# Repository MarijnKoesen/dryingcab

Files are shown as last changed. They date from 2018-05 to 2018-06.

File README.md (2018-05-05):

# Drying cabinet v2.0



This is my drying cabinet / curing chamber or just call it connected fridge which keeps the 
temperature and humidity levels (inside the fridge) stable between some configured thresholds.

I use this cabinet to make my own cured ham & dried sausage.

This project is built on an Arduino Mega in combination with a DHT22 temperature/humidity sensor, 4 way relay 
and an ESP8266 (WiFi) adapter to create the connected fridge.

For more information on design (decisions) etc, check out src/dryingcab.ino's comment at the top.

## Result

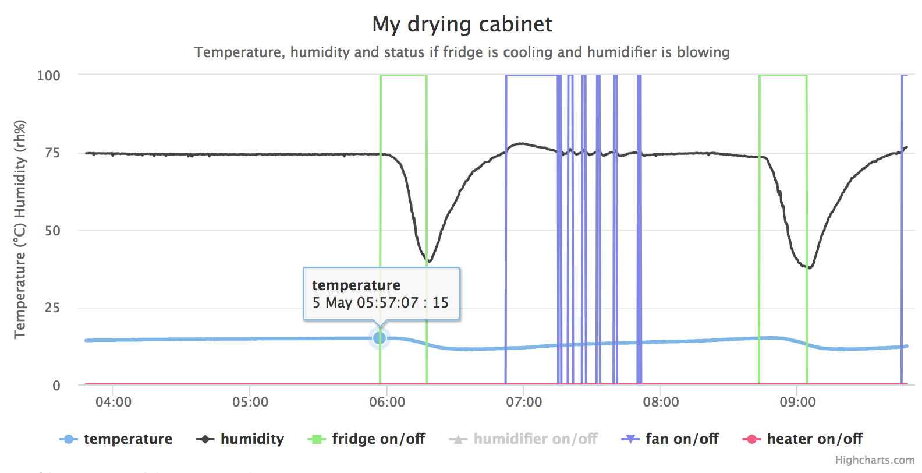
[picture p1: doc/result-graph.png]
Result graph


Here you can see some graphs from the fridge. 

Notice the temperature keeps stable between 13 and 15 degrees and the humidity
between 50 and 75 percent.

When the temperature gets too high, the fridge turns on, causing the humitity to 
drop. 

After the temperature is at the lower threshold (13), the fridge is turned off again and
the humidity starts to rise again, actually going a bit higher then we want. 

At this time the fan turns on, and blows out some of the humid air, stabalizing 
everything again. 

Now the temperature slowly rises (because it's hotter outside) until it gets above
the threshold again and the whole proces starts over.

## Connection diagram

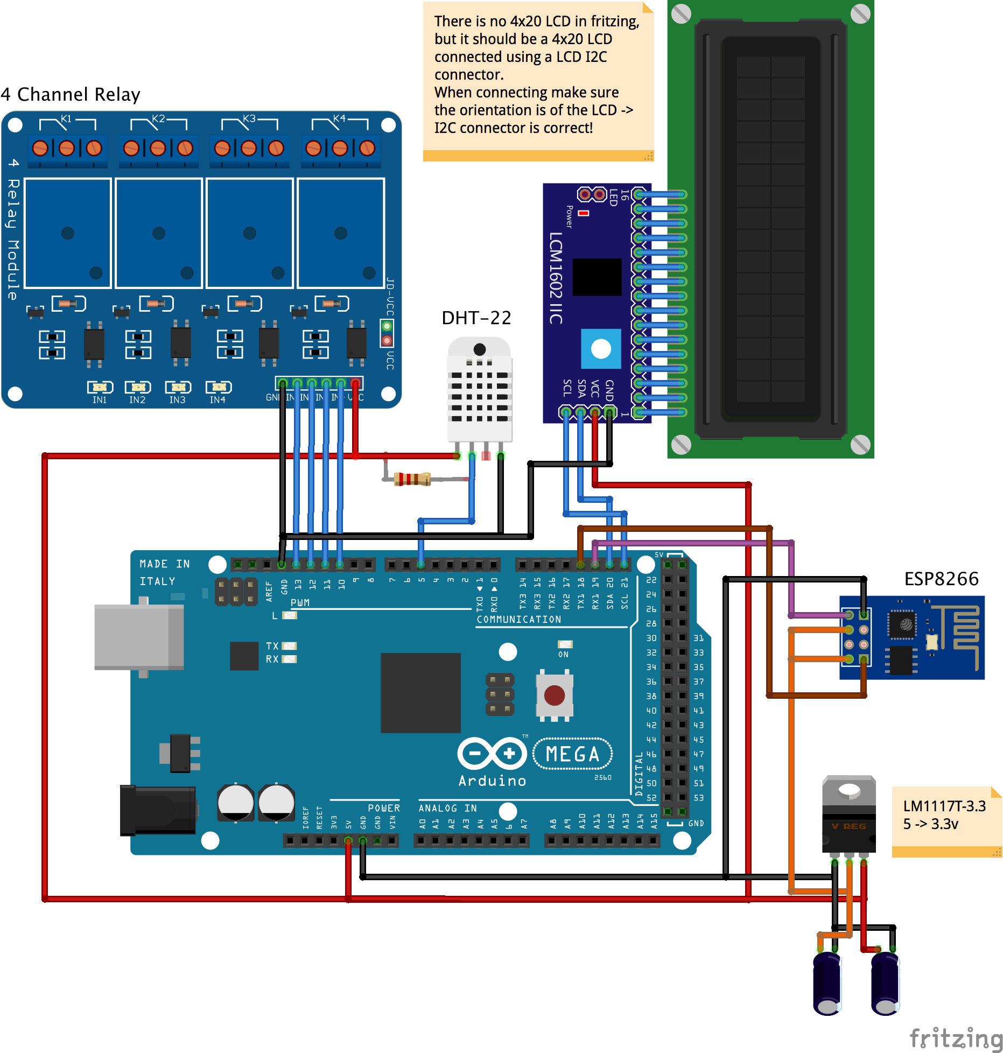
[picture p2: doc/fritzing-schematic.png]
Connection diagram


## Part list

- 1x Arduino Mega
- 1x DHT-22
- 1x [LM1117T-3.3](https://www.vanallesenmeer.nl/LM1117T-3.3-Spanningsregelaar%283.3v%29)
- 1x [20x4 LCD](https://www.vanallesenmeer.nl/LCD-Display-2004A-20x4-wit-op-blauw-)
- 1x [LCD I2C](https://www.vanallesenmeer.nl/LCD-I2C-interface-)
- 1x [ESP8266](https://www.vanallesenmeer.nl/ESP8266-Serial-Wireless-WIFI-Module)
- 1x [4 channel relay board](https://www.vanallesenmeer.nl/Relais-board-4-kanaals-5V-)
- 1x 10k resistor
- 2x 10uf cap

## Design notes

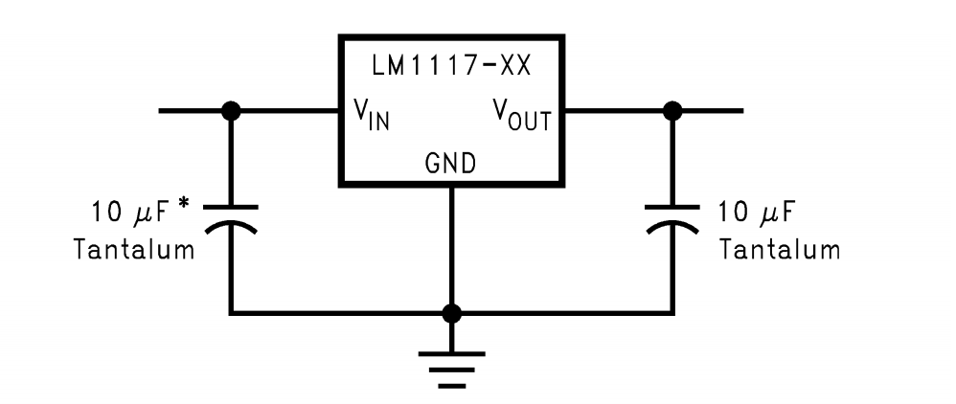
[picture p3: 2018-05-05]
doc/lm1117-schematic.png

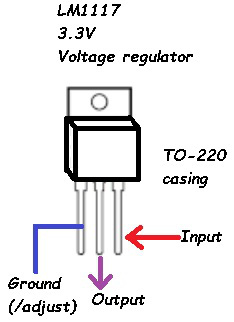
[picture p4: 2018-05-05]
doc/lm1117-3-3v-voltage-regulator-pinout.jpg

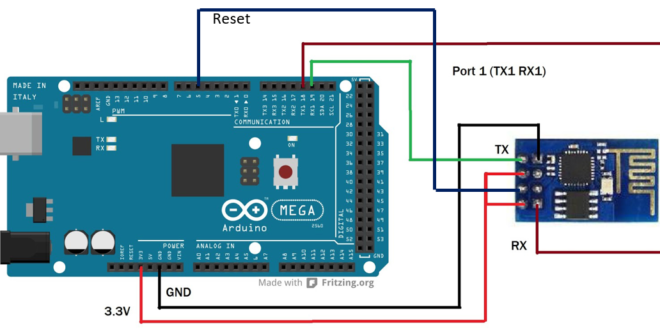
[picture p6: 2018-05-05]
doc/mega_esp8266.png

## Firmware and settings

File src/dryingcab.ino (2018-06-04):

// Drying cabinet v2.0
//
// My arduino drying / controlled environment cabinet. This software uses
// as Arduino Mega in combination with a DHT22, 4 way relay and an ESP8266
// (WiFi) adapter to created a connected fridge which keeps the temperature
// and humidity levels stable between the configured thresholds.
//
// IMPORTANT: 1) for this to work correctly we need proper watchdog support
//
// Connection instructions (see dryingcab.h for details, or to change pins):
// - Connect DHT22 data to pin 5
// - Connect the relay for the fridge to pin PIN_RELAY_FRIDGE (13)
// - Connect the relay for the humidifier to pin PIN_RELAY_HUMIDIFIER (12)
// - Connect the relay for the fan to pin PIN_RELAY_FAN (11)
// - Connect the relay for the heater (black lamp) to pin PIN_RELAY_HEATER (10)
// - Connect the relay further more to gnd and +5v
// - Connect the 4x20 I2C LCD to the SDA(20) & SCL (21), gnd and +5v
// - For further connection instructions see the connection diagram in this project (/doc)

// Notes on the algorithm:
// - 30 seconds was too long, we humidified for too long, getting a humidity that was too high
// - 15 seconds is working fine
// - We don't want to go too short, to avoid turning on the electric stuff too often/soon after shutting it down
// - When the humidity is too high we put on the fan so that we blow out wet air, and suck in new warmer, dryer air
// - To ensure we have the recommend airflow we turn the fan on for 1 second every 15 seconds, this circulates the air

// Notes about the construction:
// - About the fan:
// -- Make sure the fan is pointed so that it's sucking air out, otherwise you will get overpressure
// -- Make another hole on the opposite side (diagonally) of the fan, so that new air is sucked in there
// -- Place the fan at the top, so that it sucks warm air out
// -- Create the other (small) hole in the bottom

// My problems and challenges when developing this, what worked, and what didn't with regards to the ethernet
// - In the previous versions I was using a Enc28J60 UTP board, but there were a lot of problems with this, see previous
//   versions of this project, in this commentblock, where it's explained in more detail
// - Also I wanted to have control over de settings from the outside, without needing to re-program the fridge
//   to achieve this I wanted to add an LCD and some buttons. So I can control settings easily.
// -- Currently there is no support for the buttons though, this will be done in a later stage as the fridge is still
//    busy with my capocollo which is more important and cannot be interrupted ;-)
// - To get rid of the Enc28J60 board I decided to use the ESP8266 WiFi module instead
// - Connecting to Enc28J60 is done using a Serial connection, but since the Arduino UNO only has 1 Serial connection
//   it's hard to debug and use the WiFi at the same time. I tried to user SoftwareSerial, but that was just a PITA.
//   First because Enc28J60 doesn't really like it, as the best baud rate is 115200, but SoftwareSerial only supports
//   up to 9600. Apart from that I couldn't really get it to work. So I decided to change it, and go with Arduino Mega instead
// - Currently i'm running with watchdog enabled
// -- This may be a bit of legacy, as I needed it for the Enc28J60 board, but I think it's good practice to keep this running
//    so that for what ever reason something goes wrong/is hanging, the arduino will just be reset and will start again.
// -- The idea is that I set watchdog on 8sec, so if I don't give the watchdog an ok every 8 seconds it reboots the arduino
// - The project is developed in Atom using PlatformIO, with this setup i'm able to create a better project
//   structure with separate files, includes, libraries and a makefile that I can run. I prefer this a lot over the
//   standard Arduino IDE, which works, but I don't really like it, you can't even format source code in it for example.
// - For the WiFi I ended up using the Arduino WiFiEsp library, the stock Android library doesn't allow you to specify
//   which Serial port to use, and since I'm on a mega a want to be able to specify Serial1.
// - The ESP8266 needs 3.3V, but the Arduino can't supply enough ampere on the 3.3v port, so I read online
// -- To fix thix we need to create a voltage devider so we can go from the 5v output 3.3v
//    as the 5v output _is_ able to supply enough current
// -- To make out lives easier we're using the the LM1117T-3.3 with fixed 3.3v output
// - If I start to see problems with WiFi I can still try to hook up the reset pin of the esp8266 to a digital pin
//   on the mega, say pin 1, then you can do the following:
//     // In setup();
//     pinMode(1, OUTPUT);
//     // And thenn something like this:
//     void resetEsp() { digitalWrite(1, HIGH); delay(1000); digitalWrite(1, LOW); }
//   as per: http://www.galaxysofts.com/new/master-reset-esp8266-wifi-module-using-arduino-mega-2560/




#include "dryingcab.h"

Settings settings;
Status status;


// ==========================
// DHT (temp/humidity sensor)
// ==========================
// Initialize DHT sensor for normal 16mhz Arduino
// NOTE: For working with a faster chip, like an Arduino Due or Teensy, you
// might need to increase the threshold for cycle counts considered a 1 or 0.
// You can do this by passing a 3rd parameter for this threshold.  It's a bit
// of fiddling to find the right value, but in general the faster the CPU the
// higher the value.  The default for a 16mhz AVR is a value of 6.  For an
// Arduino Due that runs at 84mhz a value of 30 works.
// Example to initialize DHT sensor for Arduino Due:
//DHT dht(DHTPIN, DHTTYPE, 30);
#include <DHT.h>
DHT dht(PIN_DHT, DHTTYPE);

// ==========================
// Setup out periherals
// ==========================
void setup() {
    // avoid reset loops
    MCUSR = 0;

    // https://bigdanzblog.wordpress.com/2014/10/24/arduino-watchdog-timer-wdt-example-code/
    // immediately disable watchdog timer so set will not get interrupted
    wdt_disable();
    wdt_reset();

    // Now init the lcd
    lcd_init();

    // Initialize the temp+humidity sensor
    dht.begin();

    pinMode(PIN_RELAY_FRIDGE, OUTPUT);
    pinMode(PIN_RELAY_HUMIDIFIER, OUTPUT);
    pinMode(PIN_RELAY_FAN, OUTPUT);
    pinMode(PIN_RELAY_HEATER, OUTPUT);

    // We need to put the relays in an 'off' state, else they will be switched on by (Arduino's pin) default and, potentially, in the first loop
    // go off again as they don't need to be on, causing a off/on/off switch in a short amount of time which we want to prevent
    turnOff(PIN_RELAY_FRIDGE);
    turnOff(PIN_RELAY_HUMIDIFIER);
    turnOff(PIN_RELAY_FAN);
    turnOff(PIN_RELAY_HEATER);

    // And set default settings
    settings.minHumidity = 50;
    settings.maxHumidity = 75;

    settings.minTemp = 13;
    settings.maxTemp = 15;

    status.humidity = 75.7;
    status.temperature = 13.5;

    //   // The following forces a pause before enabling WDT. This gives the IDE a chance to
    //   // call the bootloader in case something dumb happens during development and the WDT
    //   // resets the MCU too quickly. Once the code is solid, remove this.
    delay(2000);
    wdt_enable(WDTO_8S);
}

// ==========================
// Our main application loop
// ==========================
void loop() {
  debugln("\n\nStarting lcd...");
  LcdOutput lcdOutput;
  debugln("Lcd started");
  debugln("Lcd outputing..");
  lcdOutput.output(status, settings);
  debugln("Lcd outputted");

  debugln("Create wifi");
  WiFiOutput wifiOutput(WIFI_NETWORK, WIFI_PASSWORD);
  debugln("Wifi created...");
  wifiOutput.connect();
  // debugln("Wifi connected...");
  // wifiOutput.output(status, settings);
  // debugln("Create outputtedd...");

  while(1) {
    readSensors();
    processSensorData();
    updateStatus();

    lcdOutput.output(status, settings);
    wifiOutput.output(status, settings);

    #ifdef DEBUG
    // Move to DebugOutput.output()
      Serial.print("Temp: ");
      Serial.println(status.temperature);

      Serial.print("Humidity: ");
      Serial.println(status.humidity);
    #endif

    // Wait for 15 seconds, and check again so that we don't turn on/off the fridge constantly
    //
    // But if we'd delay(30000) our network connection would get closed/fucked up, so we need
    // to keep the network alive by sleeping shortly, and checking for packets, this way the
    // network stays alive
    int sleepInSeconds = 15;

    for (int i = 0; i < sleepInSeconds; i++) {
      // Reset the watchdog, so that the arduino will not get reset
      wdt_reset();

      delay(1000);

      if (status.statusFan == true) {
        // If we have a high humidity and the fan is already on, keep the fan on for 15 seconds, to try to get the humidity down
      } else {
        // If we have a proper humidity, turn the fan on for 1 second every 15 seconds to ensure we have some airflow
        switch(i) {
          case 0:
            turnOn(PIN_RELAY_FAN);
            break;

          case 1:
            turnOff(PIN_RELAY_FAN);
            break;
        }
      }
    }
  }
}

void readSensors() {
  status.temperature = getTemperatureInCelcius();
  status.humidity = getHumidity();
}

void processSensorData() {
  if (status.temperature >= settings.maxTemp) {
    turnOn(PIN_RELAY_FRIDGE);
  }

  if (status.temperature < settings.minTemp) {
    turnOff(PIN_RELAY_FRIDGE);
  }

 if (status.humidity < settings.minHumidity) {
    turnOn(PIN_RELAY_HUMIDIFIER);
  }

  if (status.humidity > settings.maxHumidity) {
    turnOff(PIN_RELAY_HUMIDIFIER);
  }

  if (status.humidity > settings.maxHumidity) {
    // Currently the outside humidity is higher then inside the fridge
    // so turning on the fan only makes it worse.
    // TODO: add another temp/humidty sensor outside of the fridge, and only
    // turn on the fan is the outside humidity is lower than inside
    //turnOn(PIN_RELAY_FAN);
  } else {
    //turnOff(PIN_RELAY_FAN);
  }
}

void updateStatus() {
  status.statusFridge = digitalRead(PIN_RELAY_FRIDGE) == LOW;
  status.statusHumidifier = digitalRead(PIN_RELAY_HUMIDIFIER) == LOW;
  status.statusFan = digitalRead(PIN_RELAY_FAN) == LOW;
  status.statusHeater = digitalRead(PIN_RELAY_HEATER) == LOW;
}

//
// int failedLogTries = 0;
// void sendLogData() {
//   // generate two fake values as payload - by using a separate stash,
//   // we can determine the size of the generated message ahead of time
//   #ifdef DEBUG
//   Serial.println(F("GO"));
//   #endif
//
// //   if (client.connect(server, 80)) {
// //     client.print(F("GET /push-status.php?"));
// //
// //     client.print(F("temperature="));
// //     client.print(logData.fridgeTemperature);
// //
// //     client.print(F("&humidity="));
// //     client.print(logData.humidity);
// //
// //     client.print(F("&status_fridge="));
// //     client.print(logData.statusFridge == 1 ? F("1") : F("0"));
// //
// //     client.print(F("&status_humidifier="));
// //     client.print(logData.statusHumidifier == 1 ? F("1") : F("0"));
// //
// //     client.print(F("&status_fan="));
// //     client.print(logData.statusFan == 1 ? F("1") : F("0"));
// //
// //     client.print(F("&status_heater="));
// //     client.print(logData.statusHeater == 1 ? F("1") : F("0"));
// //
// //     client.print(F(" HTTP/1.1\n"));
// //
// //     client.print(F("HOST: droogkast.pruts0r.nl\n\n"));
// //     client.stop();
// //   } else {
// //     #ifdef DEBUG
// //     Serial.println(F("ERROR: Cannot connect to server to push status! Restarting the Enc28J60.."));
// //     #endif
// //
// //     failedLogTries++;
// //     if (failedLogTries > 3) {
// //       reboot = true;
// //     }
// //
// //     // Try to re-init our network module if it fails, next time round it should be fine again...
// //     // Found: http://www.tweaking4all.com/hardware/arduino/arduino-enc28j60-ethernet/
// //     client.stop();
// //     //Enc28J60.init(mymac);
// //   }
// }
//
//
// // void connectLanWithDhcp() {
// // #ifdef DEBUG
// //   Serial.println(F("Starting network connection..."));
// // #endif
// //
// //   Ethernet.begin(mymac);
// //
// // #ifdef DEBUG
// //   Serial.println(F("Network started.]"));
// //   Serial.print(F("IP Address        : "));
// //   Serial.println(Ethernet.localIP());
// //   Serial.print(F("Subnet Mask       : "));
// //   Serial.println(Ethernet.subnetMask());
// //   Serial.print(F("Default Gateway IP: "));
// //   Serial.println(Ethernet.gatewayIP());
// //   Serial.print(F("DNS Server IP     : "));
// //   Serial.println(Ethernet.dnsServerIP());
// // #endif
// // }

void turnOn(int pin)
{
  digitalWrite(pin, LOW);
}

void turnOff(int pin)
{
  digitalWrite(pin, HIGH);
}

float getTemperatureInCelcius()
{
  return dht.readTemperature();
}

/**
 * Reading temperature or humidity takes about 250 milliseconds!
 * Sensor readings may also be up to 2 seconds 'old' (its a very slow sensor)
 */
float getHumidity()
{
  return dht.readHumidity();
}

void showDebugModeOnLcd()
{
  lcd.clear();
  lcd.setCursor(0, 0);
  lcd.print(F("RUNNING IN DEBUG MODE!!"));
}

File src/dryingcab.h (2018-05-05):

#ifndef DRYINGCAB_H
#define DRYINGCAB_H

// Arduino includes
#include <Arduino.h>
#include <avr/wdt.h> // Watchdog

// DryincCab includes
#include "Settings.h"
#include "WiFiConfig.h"
#include "Status.h"
#include "Output/LcdOutput.h"
#include "Output/WiFiOutput.h"

// ========================
// RELAY
// ========================

#define PIN_RELAY_FRIDGE        13
#define PIN_RELAY_HUMIDIFIER    12
#define PIN_RELAY_FAN           11
#define PIN_RELAY_HEATER        10

// ========================
// THERMOMETER / HYDROMETER
// ========================

#define PIN_DHT 5       // what pin we're connected to
#define DHTTYPE DHT22   // DHT11 or DHT22

// ========================
// DEBUG
// ========================

// To enable/disable debugging go to Debug.h
#include "Debug.h"


#endif

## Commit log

2018-05-05 Version 2, big rewrite
    [fritzing-schematic.fzz]
2018-06-04 Don't turn on the fan with too high humidity
    Because mostly likely the outside humidity is higher anyway, also
    I tried to turn on the heater, but that heats too much and will
    cause all other sorts of problems (way to warm meat/cheese) so
    don't use the heater until you can make indirect heat and have
    it produce less then currently is the case
    [dryingcab.ino]
